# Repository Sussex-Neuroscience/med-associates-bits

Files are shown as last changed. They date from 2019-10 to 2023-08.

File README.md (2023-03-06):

# Med Associates open source add ons and bits

 Med Associates sells a number of tools for behavioural systems. This commercial system is a complete solution for behavioural experiments, and can be used to run multiple behavioural boxes in parallel. It is unfortunately rather expensive and closed source, so users are almost always dependent on MedAssociates for upgrades and customization (and whenever something breaks). Another downside is that an unusual 28V system is employed, so adding/customizing things has an extra layer of complexity.

 This repository is a collection of bits, add-ons and some knowledge on the system we have gathered over the years.
 
### [License](./LICENSE)

### [Code of Conduct](./code_of_conduct.md)

### [Contributing](./contributing.md)

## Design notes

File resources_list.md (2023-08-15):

# A list with links and descriptions of useful resources.

|item|link|obs|
|--|--|--|
|clickers|https://uk.rs-online.com/web/p/power-relays/6133617|any relay capable of handling 24V as the trigger for the coil should be able to do the trick, make sure to attach a diode, like one from ln400X family|
|cable connector housing male|||
|cable connector|https://uk.rs-online.com/web/p/crimp-contacts/2363044/||
||||
||||
||||

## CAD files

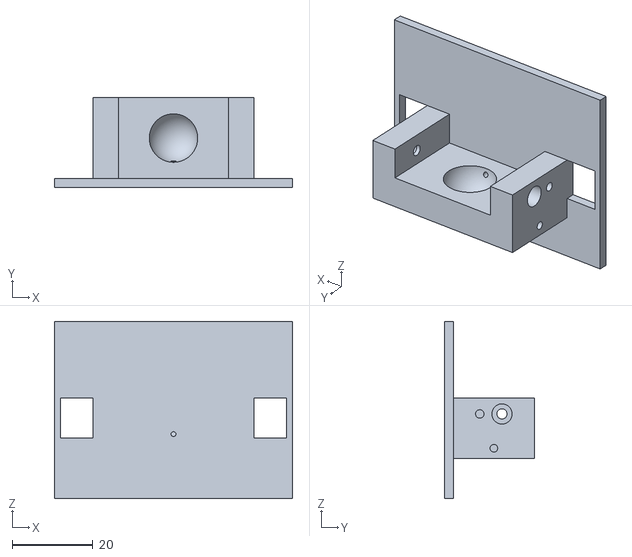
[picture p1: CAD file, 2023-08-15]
hardware/Head entry draft 2.stl
59.0 x 22.2 x 44.0

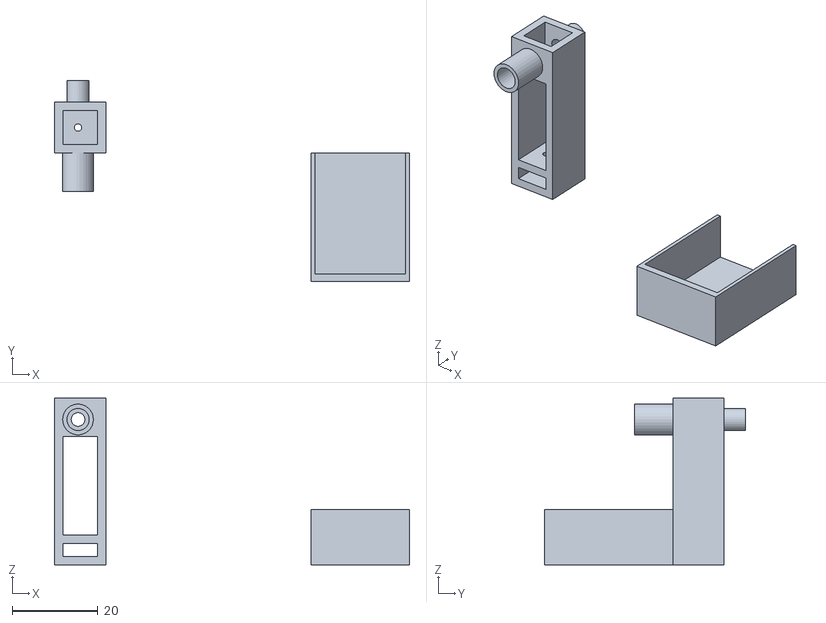
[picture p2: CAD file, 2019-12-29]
hardware/liking_spout/supports.stl
83.0 x 47.0 x 39.0

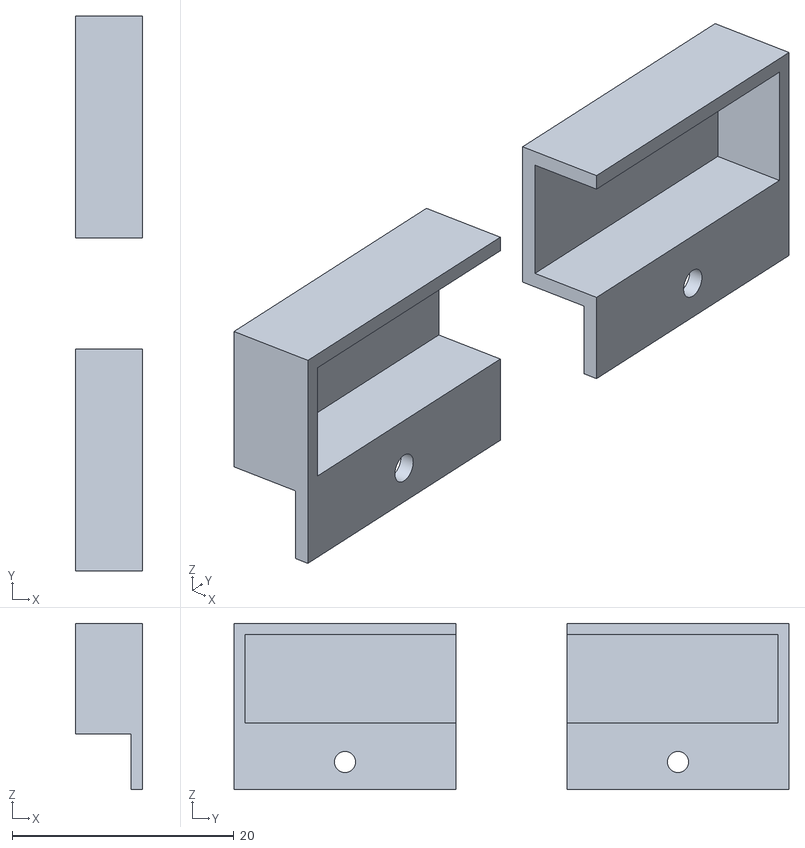
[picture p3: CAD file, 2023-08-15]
hardware/head entry photocell protectors.stl
6.00 x 50.0 x 15.0

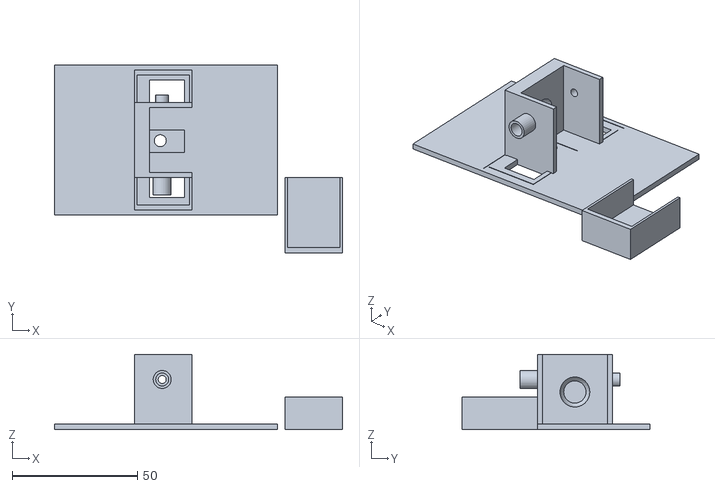
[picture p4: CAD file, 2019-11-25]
hardware/liking_spout/licking_spout_photometry.stl
115.0 x 74.9 x 30.0

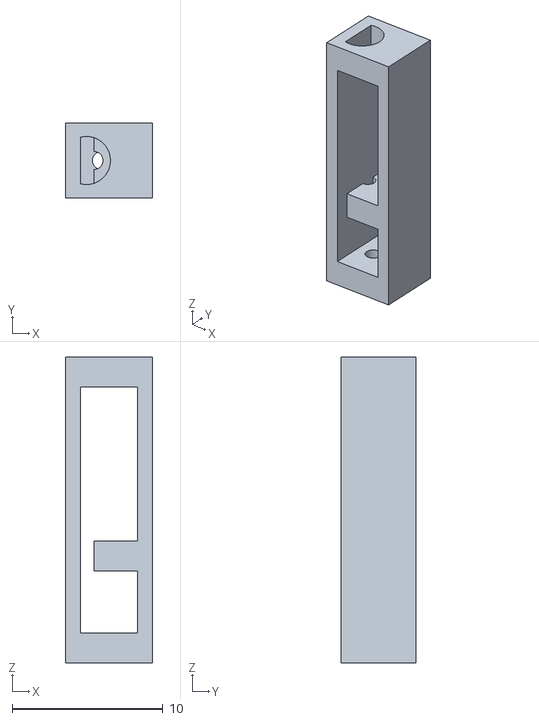
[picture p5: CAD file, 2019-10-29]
hardware/liking_spout/test1.stl
5.80 x 5.00 x 20.3

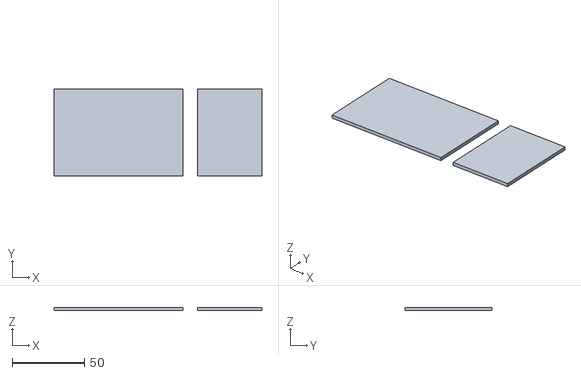
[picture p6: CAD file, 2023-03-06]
hardware/plates.stl
143.5 x 60.0 x 2.30

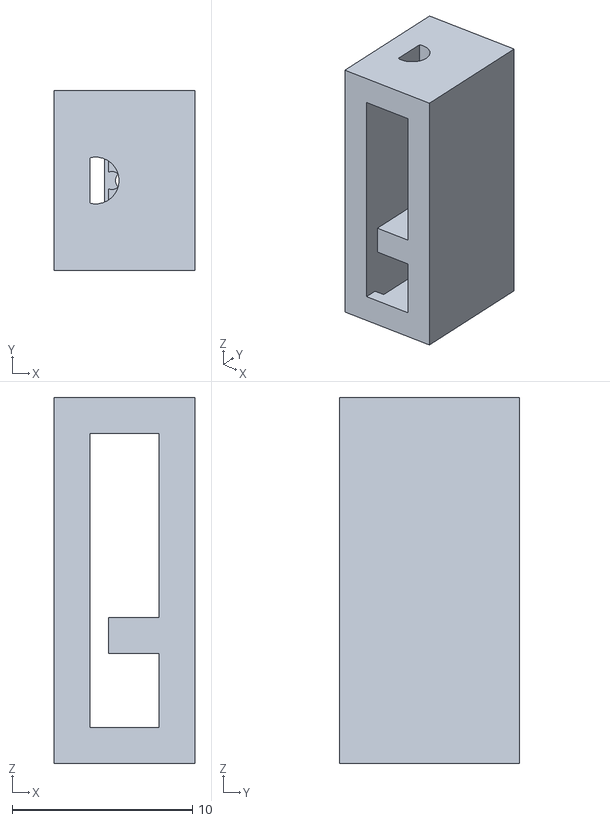
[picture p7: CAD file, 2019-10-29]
hardware/liking_spout/test.stl
7.80 x 10.0 x 20.3

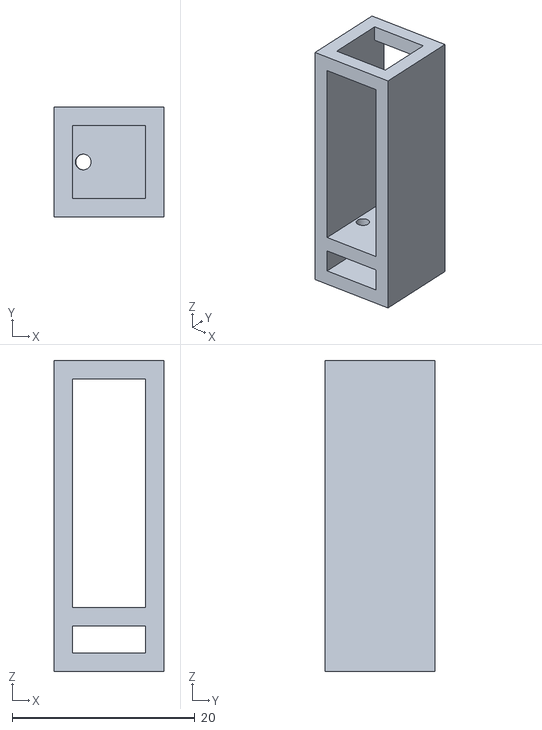
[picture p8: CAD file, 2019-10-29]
hardware/liking_spout/licking_spout_tilted.stl
12.0 x 12.0 x 34.0

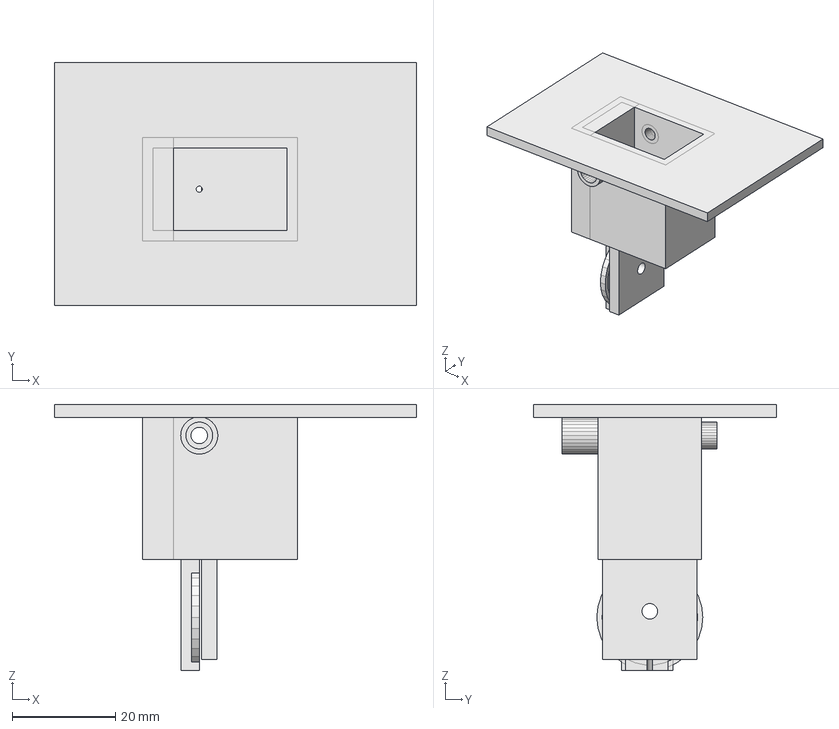
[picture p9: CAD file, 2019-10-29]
hardware/liking_spout/licking_spout.FCStd
70.0 x 47.0 x 51.5 mm

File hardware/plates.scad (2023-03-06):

tol = 0.1;
lPlateL = 89;
sPlateL = 44.5;
plateW = 60;


plateT = 2.3;

cube([lPlateL,plateW,plateT]);

translate([lPlateL+10,0,0])
cube([sPlateL,plateW,plateT]);

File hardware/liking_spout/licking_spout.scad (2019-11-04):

///////////////////////////////////////////
// Design for a liking spout to be used  //
// in the behaviour box                  //
//  CC-BY-SA 4.0 20191008                //
//  Andre Maia Chagas                    //
///////////////////////////////////////////

// all dimensions in mm.

//needs the ring.scad file (saved on the same folder)
use <ring.scad>

//// variables /////////////

//needle used as licking spout
needlediameter = 1.53;

//back plate dimensions 
//(the plate that slides on the metal railings)
backpanelx = 44.5*2;
backpanely = 59.80;
backpanelz = 2.15;

supportw=5;

//dimensions for the headport 
//(a "negative" space where the licking spout will be placed)
headportx = 30;
headporty = 20;
headportz = 30;
lickspoutoffset = 5;
//wall thickness
headportwall = 2;


//force sensor dimensions
forcesensord = 18.3;
forcesensorh = 0.8;
forcesensorl = 33; //how long the long part of the sensor
forcesensorw = 8; // wiidth of the long part of the sensor

//infrared led dimensions
irrecd = 3;
irrech = 5;
irledd = 5;
irledh = 9;

//nut & screw infor
screwd = 3.2;
nutd = 5;

/* change this depending on the printer and printer settings
   it is a "tolerance" variable, so holes and fittings can be 
   adjusted.
*/
tol = 0.1;

$fn=30;
//%cube([backpanelx,backpanely,backpanelz]);


//supporting modules
module irholes(){
    rotate([90,0,0]){
        translate([0,0,0]){
            cylinder(d=irledd+2*tol,h=irledh);
        }//end translate
        translate([0,0,-headporty]){    
            cylinder(d=irrecd+2*tol,h=irledh);
        }//end translate
     }//end rotate
}//end module ir holes

module irsupports(){
rotate([90,0,0]){
    translate([0,0,headportwall]){
ring(irledd+2*tol,2,irledh);
    }//end translate
translate([0,0,-headporty+headportwall/2]){    
    ring(irrecd+2*tol,2,irrech);
    }//end translate
}//end rotate
}//end module ir holes



module fsensorholder(){
difference(){
union(){
    cylinder(d=forcesensord+2*tol+headportwall,h=forcesensorh+headportwall/2);
    translate([-4.5,-13,-2]){
        cube([forcesensorw+headportwall,forcesensord+5,forcesensorh+headportwall/2+2]);
    }//end translate
}//end union

union(){
    translate([0,0,forcesensorh/2+headportwall/2]){
        cylinder(d=forcesensord+2*tol,h=forcesensorh);
    }//end translate
    translate([(-forcesensorw+headportwall/2)/2,0,(forcesensorh+headportwall)/2]){
        cube([forcesensorw+2*tol,forcesensorl+headportwall,5]);
    }//end translate
    translate([needlediameter/2,headporty/2+2,needlediameter/4+headportwall/2]){
        rotate([90,0,0]){
            cylinder(d=needlediameter+2*tol,h=55);
        }//end rotate
    }//end translate
}//end union

}//end difference

}//end module



/////////////////////////////
module needlesupport(){
    module mainframe(){
difference(){
cube([8+2*headportwall,forcesensorw+2*headportwall,35+2*headportwall]);
translate([headportwall,-headportwall,headportwall]){
cube([8,forcesensorw+4*headportwall,28]);
}//end translate
}//end difference
translate([headportwall,0,5]){
cube([8,forcesensorw+2*headportwall,headportwall]);
}//end translate
}//end submodule

difference(){
mainframe();
//translate([13.5,(forcesensorw+2*headportwall)/2,12]){
//rotate([0,90,0]){    
//%cylinder(d=nutd+2*tol,h=4,$fn=6);
//    translate([0,0,-6]){
//cylinder(d=screwd,h=12);
//}//rotate
//}//translate
//cube([nutd,nutd+10,nutd+tol],center=true);
//}//translate
translate([irrecd/2+2*headportwall,(forcesensorw+2*headportwall)/2,-headportwall-1]){
    rotate([0,0,0]){
        cylinder(d=needlediameter+2*tol,h=20);
    }//end rotate
    translate([0,0,35+headportwall]){
    rotate([90,0,0]){
        
        cylinder(d=irledd+2*tol,h=20);
        
    }//end rotate
    rotate([-90,0,0]){
        
        cylinder(d=irrecd+2*tol,h=20);
        
    }//end rotate
    }//end translate
}//end translate



translate([headportwall,headportwall,10]){
        cube([8,forcesensorw,30]);
        
    }//end translate
    
}//end difference
translate([(8+headportwall)/2+0.5,0,35+headportwall-irledd/2-0.5]){
rotate([90,0,0]){
ring(irledd+2*tol,2,irledh);
}//end rotate
}//end translate
translate([(8+headportwall)/2+0.5,forcesensorw+2*headportwall,35+headportwall-irrecd]){
rotate([-90,0,0]){
ring(irrecd+2*tol,2,irrech);

}//end rotate
}//end translate
//}//end translate
}//end module




/////////////////////////////
module lickingport(){
//head port
difference(){
cube([headportx,headporty,headportz]);
    
    
union(){    
translate([headportwall,headportwall,headportwall]){
cube([headportx-headportwall*2,headporty-headportwall*2,headportz]);
}//end translate


//needle entry
translate([headportx/5+lickspoutoffset-needlediameter/2,(headporty-headportwall+needlediameter)/2,-35]){
    cylinder(d=3*needlediameter+2*tol,h=50);
    }//end translate
 
    //led side ports
    translate([headportx/5+5,headportwall+2,4*headportz/5]){
        irholes();
    }//end translate
}//end union
}//end difference
///////////////////////

////////////////////////////
    
///////////////////////////
//base plate with round liquid reservoir


difference(){ 
cube([headportx/5,headporty,headportz]);
translate([headportx/5,headporty/2,3*headportz/6]){
    sphere(d=12);
    }//end translate
}//end difference
    
////////////////////////////

translate([headportx/5+5,headportwall+2,4*headportz/5]){
irsupports();
}
}//end licking port


module backpanel(){
difference(){
translate([-(headportx+2*headportwall)/2,-backpanely/2+headporty/2,headportz-headportwall-0.15]){

cube([backpanelx,backpanely,backpanelz]);
    

}
translate([0,0,5]){
cube([headportx,headporty,headportz]);
}//end transalte
}//end difference
}//end module


///////////////////////////
lickingport();
backpanel();
///////////////////////////

translate([5,headporty/2-(forcesensorw+2*headportwall)/2,-(35+2*headportwall)]){
//rotate([0,0,180]){
//fsensorholder();
needlesupport();
//}//end rotate
}//end translate


//
//needlesupport();

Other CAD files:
hardware/liking_spout/licking_spout_photometry.scad
hardware/liking_spout/ring.scad
hardware/liking_spout/licking_spout.stl

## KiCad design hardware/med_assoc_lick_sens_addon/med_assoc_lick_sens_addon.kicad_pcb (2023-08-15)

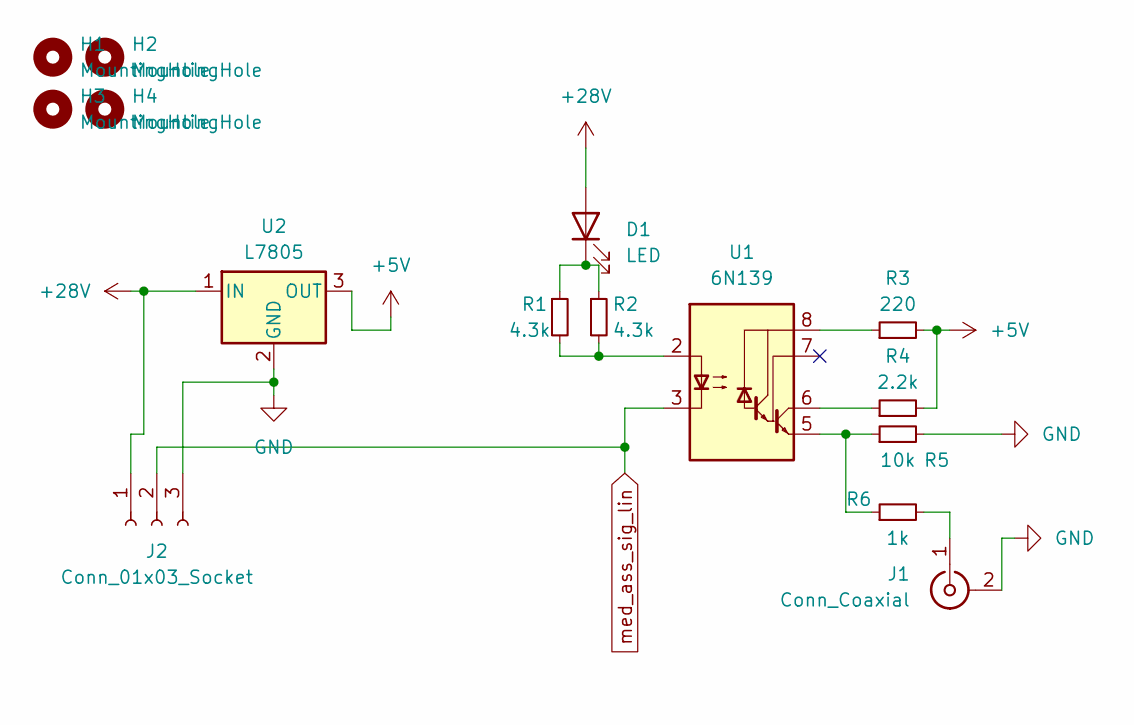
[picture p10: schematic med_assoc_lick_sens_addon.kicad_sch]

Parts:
D1: LED; LED_D5.0mm
H1, H2, H3, H4: MountingHole; MountingHole_3.2mm_M3
J1: Conn_Coaxial; TerminalBlock_Altech_AK300-2_P5.00mm
J2: Conn_01x03_Socket; TerminalBlock_Altech_AK300-3_P5.00mm
R1, R2: 4.3k; R_Axial_DIN0309_L9.0mm_D3.2mm_P12.70mm_Horizontal
R3: 220; R_Axial_DIN0309_L9.0mm_D3.2mm_P12.70mm_Horizontal
R4: 2.2k; R_Axial_DIN0309_L9.0mm_D3.2mm_P12.70mm_Horizontal
R5: 10k; R_Axial_DIN0309_L9.0mm_D3.2mm_P12.70mm_Horizontal
R6: 1k; R_Axial_DIN0309_L9.0mm_D3.2mm_P12.70mm_Horizontal
U1: 6N139; DIP-8_W7.62mm_LongPads
U2: L7805; TO-220-3_Vertical

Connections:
+5V: R3.2, R4.2, U2.3 (OUT)
+28V: D1.2 (A), J2.1, U2.1 (IN)
GND: J1.2 (Ext), J2.3, R5.2, U2.2 (GND)
unnamed: D1.1 (K), R1.1, R2.1
unnamed: J1.1 (In), R6.2
unnamed: R1.2, R2.2, U1.2 (C1)
unnamed: R5.1, R6.1, U1.5 (GND)
unnamed: R3.1, U1.8 (VCC)
unnamed: R4.1, U1.6 (VO2)
med_ass_sig_lin: J2.2, U1.3 (C2)

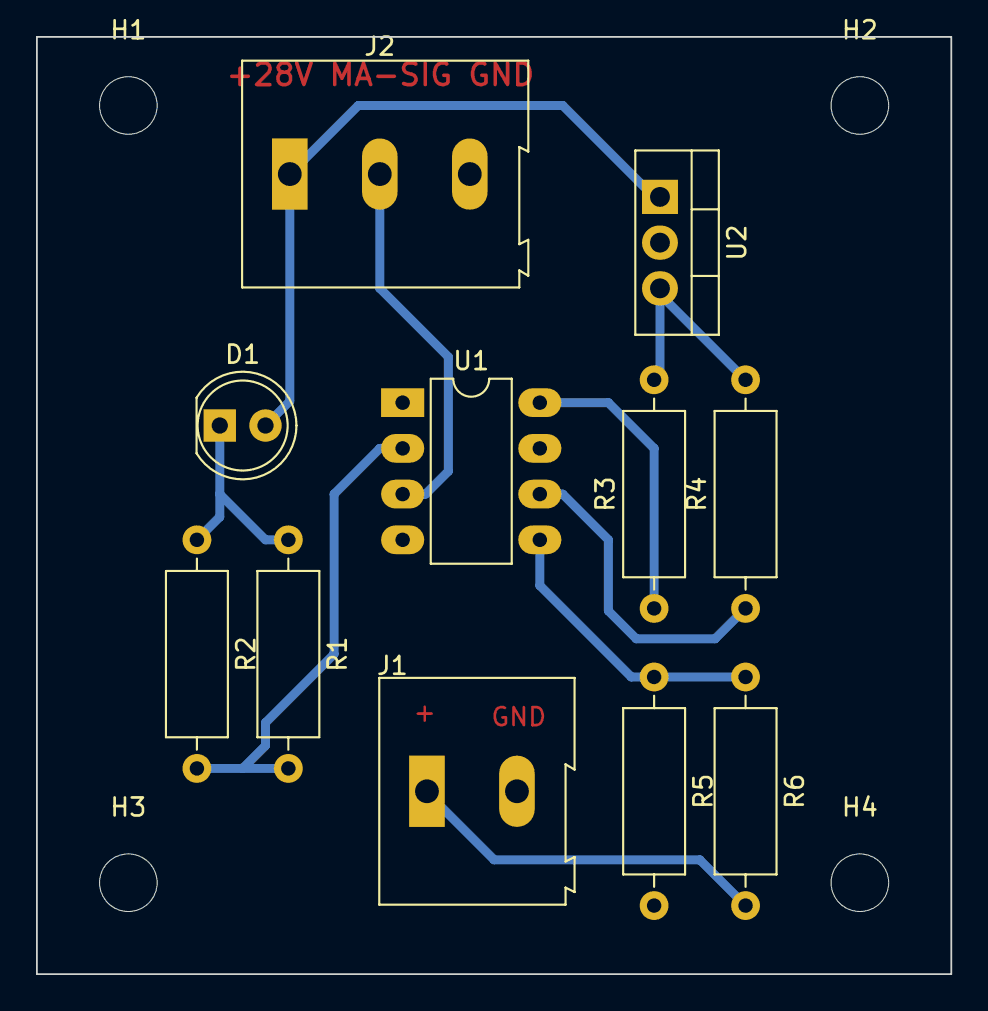
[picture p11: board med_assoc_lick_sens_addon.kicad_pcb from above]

Board: 2 copper layers, 50.8 x 52.1 mm, 15 parts (0 on the bottom side), 10 nets.

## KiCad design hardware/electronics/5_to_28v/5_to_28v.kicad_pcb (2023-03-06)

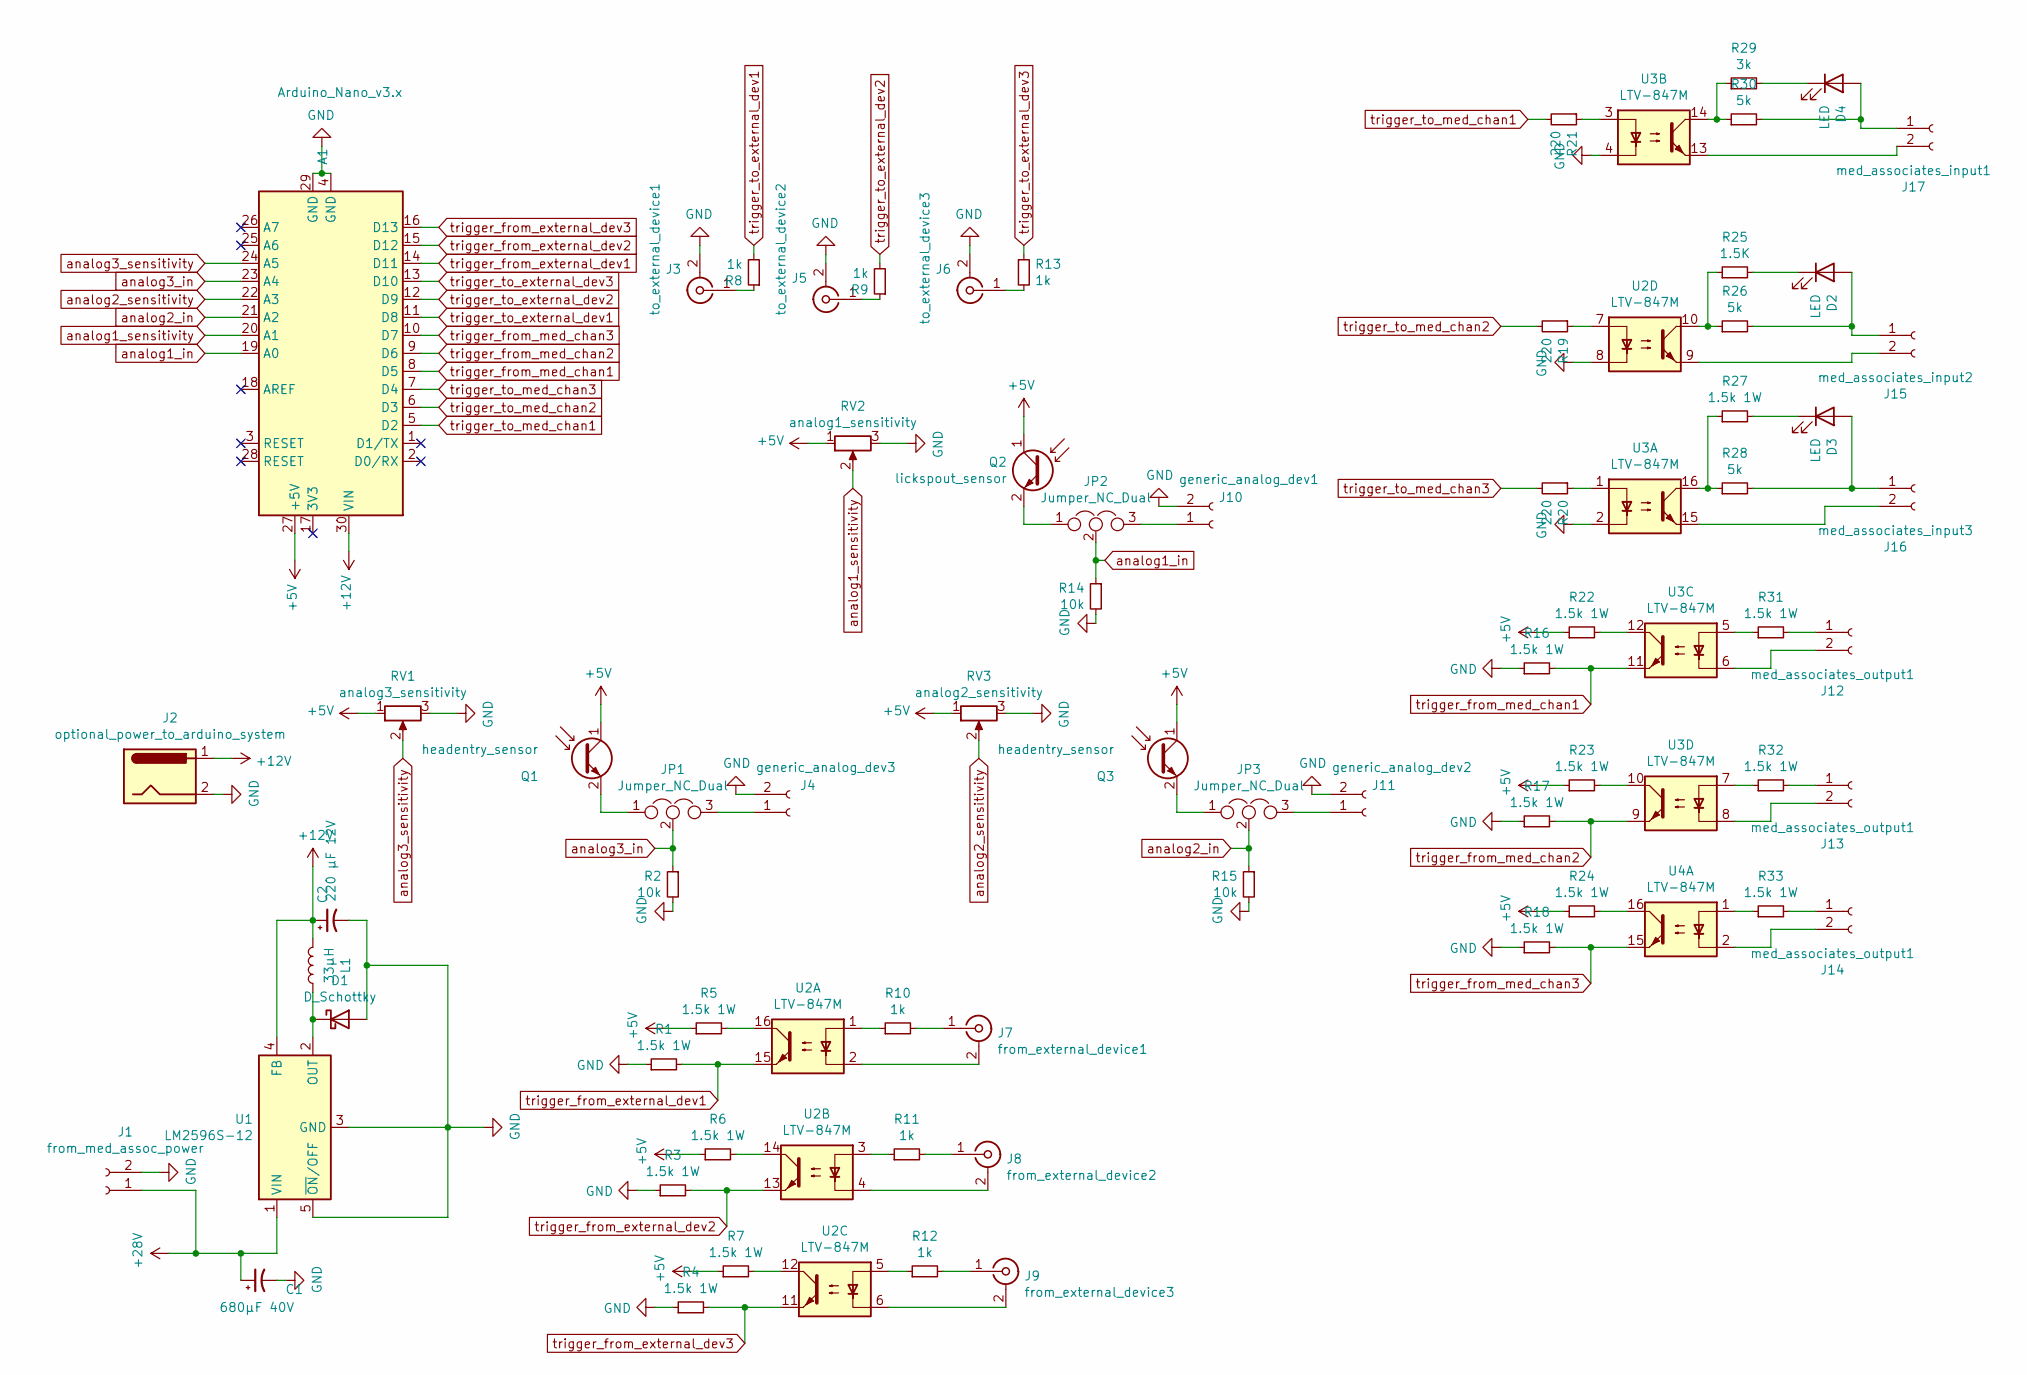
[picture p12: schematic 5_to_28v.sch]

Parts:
A1: Arduino_Nano_v3.x; Arduino_Nano
C1: 680µF 40V; CP_Radial_D10.0mm_P5.00mm_P7.50mm
C2: 220 µF 12V; CP_Radial_D10.0mm_P5.00mm_P7.50mm
D1: D_Schottky; D_DO-27_P15.24mm_Horizontal
D2, D3, D4: LED; LED_D5.0mm
J1: from_med_assoc_power; JST_XH_B2B-XH-A_1x02_P2.50mm_Vertical
J2: optional_power_to_arduino_system; BarrelJack_Horizontal
J3: to_external_device1; JST_XH_B2B-XH-A_1x02_P2.50mm_Vertical
J4: generic_analog_dev3; JST_XH_B2B-XH-A_1x02_P2.50mm_Vertical
J5: to_external_device2; JST_XH_B2B-XH-A_1x02_P2.50mm_Vertical
J6: to_external_device3; JST_XH_B2B-XH-A_1x02_P2.50mm_Vertical
J7: from_external_device1; JST_XH_B2B-XH-A_1x02_P2.50mm_Vertical
J8: from_external_device2; JST_XH_B2B-XH-A_1x02_P2.50mm_Vertical
J9: from_external_device3; JST_XH_B2B-XH-A_1x02_P2.50mm_Vertical
J10: generic_analog_dev1; JST_XH_B2B-XH-A_1x02_P2.50mm_Vertical
J11: generic_analog_dev2; JST_XH_B2B-XH-A_1x02_P2.50mm_Vertical
J12, J13, J14: med_associates_output1; JST_XH_B2B-XH-A_1x02_P2.50mm_Vertical
J15: med_associates_input2; JST_XH_B2B-XH-A_1x02_P2.50mm_Vertical
J16: med_associates_input3; JST_XH_B2B-XH-A_1x02_P2.50mm_Vertical
J17: med_associates_input1; JST_XH_B2B-XH-A_1x02_P2.50mm_Vertical
JP1, JP2, JP3: Jumper_NC_Dual; PinHeader_1x03_P2.54mm_Vertical
L1: 33µH; L_Radial_D7.5mm_P3.50mm_Fastron_07P
Q1, Q3: headentry_sensor; LED_D5.0mm
Q2: lickspout_sensor; LED_D5.0mm
R1, R3, R4, R5, R6, R7, R16, R17, R18, R22, R23, R24, R27, R31, R32, R33: 1.5k 1W; R_Axial_DIN0516_L15.5mm_D5.0mm_P25.40mm_Horizontal
R2, R14, R15: 10k; R_Axial_DIN0516_L15.5mm_D5.0mm_P25.40mm_Horizontal
R8, R9, R10, R11, R12, R13: 1k; R_Axial_DIN0411_L9.9mm_D3.6mm_P15.24mm_Horizontal
R19, R20, R21: 220; R_Axial_DIN0411_L9.9mm_D3.6mm_P15.24mm_Horizontal
R25: 1.5K; R_Axial_DIN0516_L15.5mm_D5.0mm_P25.40mm_Horizontal
R26, R28, R30: 5k; R_Axial_DIN0516_L15.5mm_D5.0mm_P25.40mm_Horizontal
R29: 3k; R_Axial_DIN0516_L15.5mm_D5.0mm_P25.40mm_Horizontal
RV1: analog3_sensitivity; JST_XH_B3B-XH-A_1x03_P2.50mm_Vertical
RV2: analog1_sensitivity; JST_XH_B3B-XH-A_1x03_P2.50mm_Vertical
RV3: analog2_sensitivity; JST_XH_B3B-XH-A_1x03_P2.50mm_Vertical
U1: LM2596S-12; TO-220-5_P3.4x3.7mm_StaggerOdd_Lead3.8mm_Vertical
U2, U3, U4: LTV-847M; DIP-16_W10.16mm

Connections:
+5V: A1.27 (+5V), Q1.1 (C), Q2.1 (C), Q3.1 (C), R5.1, R6.1, R7.1, R22.1, R23.1, R24.1, RV1.1, RV2.1, RV3.1
+12V: A1.30 (VIN), C2.1, J2.1, L1.2, U1.4 (FB)
+28V: C1.1, J1.1, U1.1 (VIN)
GND: A1.4 (GND), A1.29 (GND), C1.2, C2.2, D1.2 (A), J1.2, J2.2, J3.2 (Ext), J4.2, J5.2 (Ext), J6.2 (Ext), J10.2, J11.2, R1.1, R2.2, R3.1, R4.1, R14.2, R15.2, R16.1, R17.1, R18.1, RV1.3, RV2.3, RV3.3, U1.3 (GND), U1.5 (~ON~/OFF), U2.8, U3.2, U3.4
unnamed: D1.1 (K), L1.1, U1.2 (OUT)
unnamed: D2.1 (K), R25.2
unnamed: D2.2 (A), J15.1, R26.2
unnamed: D3.1 (K), R27.2
unnamed: D3.2 (A), J16.1, R28.2
unnamed: D4.1 (K), R29.2
unnamed: D4.2 (A), J17.1, R30.2
unnamed: J3.1 (In), R8.1
unnamed: J4.1, JP1.3
unnamed: J5.1 (In), R9.1
unnamed: J6.1 (In), R13.2
unnamed: J7.1 (In), R10.2
unnamed: J7.2 (Ext), U2.2
unnamed: J8.1 (In), R11.2
unnamed: J8.2 (Ext), U2.4
unnamed: J9.1 (In), R12.2
unnamed: J9.2 (Ext), U2.6
unnamed: J10.1, JP2.3
unnamed: J11.1, JP3.3
unnamed: J12.1, R31.2
unnamed: J12.2, U3.6
unnamed: J13.1, R32.2
unnamed: J13.2, U3.8
unnamed: J14.1, R33.2
unnamed: J14.2, U4.2
unnamed: J15.2, U2.9
unnamed: J16.2, U3.15
unnamed: J17.2, U3.13
unnamed: JP1.1, Q1.2 (E)
unnamed: JP2.1, Q2.2 (E)
unnamed: JP3.1, Q3.2 (E)
unnamed: R5.2, U2.16
unnamed: R6.2, U2.14
unnamed: R7.2, U2.12
unnamed: R10.1, U2.1
unnamed: R11.1, U2.3
unnamed: R12.1, U2.5
unnamed: R19.1, U2.7
unnamed: R20.1, U3.1
unnamed: R21.1, U3.3
unnamed: R22.2, U3.12
unnamed: R23.2, U3.10
unnamed: R24.2, U4.16
unnamed: R25.1, R26.1, U2.10
unnamed: R27.1, R28.1, U3.16
unnamed: R29.1, R30.1, U3.14
unnamed: R31.1, U3.5
unnamed: R32.1, U3.7
unnamed: R33.1, U4.1
analog1_in: A1.19 (A0), JP2.2, R14.1
analog1_sensitivity: A1.20 (A1), RV2.2
analog2_in: A1.21 (A2), JP3.2, R15.1
analog2_sensitivity: A1.22 (A3), RV3.2
analog3_in: A1.23 (A4), JP1.2, R2.1
analog3_sensitivity: A1.24 (A5), RV1.2
trigger_from_external_dev1: A1.14 (D11), R1.2, U2.15
trigger_from_external_dev2: A1.15 (D12), R3.2, U2.13
trigger_from_external_dev3: A1.16 (D13), R4.2, U2.11
trigger_from_med_chan1: A1.8 (D5), R16.2, U3.11
trigger_from_med_chan2: A1.9 (D6), R17.2, U3.9
trigger_from_med_chan3: A1.10 (D7), R18.2, U4.15
trigger_to_external_dev1: A1.11 (D8), R8.2
trigger_to_external_dev2: A1.12 (D9), R9.2
trigger_to_external_dev3: A1.13 (D10), R13.1
trigger_to_med_chan1: A1.5 (D2), R21.2
trigger_to_med_chan2: A1.6 (D3), R19.2
trigger_to_med_chan3: A1.7 (D4), R20.2

Board: 2 copper layers, 71 parts (0 on the bottom side), 71 nets, no tracks yet.

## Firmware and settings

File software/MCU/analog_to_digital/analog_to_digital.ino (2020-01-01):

////////////////////////////////////////////////////////
// Adaptor system for Med Associates behavioural box  //
// This code is to be used to convert  analog signals //
// to digital.                                        //
// it takes analog inputs, and compares them to user  //
// defined thresholds (set via potentiometers or      //
// software), and outputs digital signals             //
// there are also indicator digital signals that are  //
// turned on together with the output signals         //
//                                                    //
// Created by AM Chagas 20191210 CC BY SA             //
////////////////////////////////////////////////////////


//define pins///////////////////////////////

//analog input ports//////
// infrared detectors
int IRrecPin = A0;
int IRrecPin1 = A2;
//potentiomenter pin
int comparatorPin = A1;
//digital output 0
int digOutPin = 13;
// digital output 1
int digOutPin1 = 12;
// led indicator 0
int ledInd = 2;
// led indicator 1
int ledInd1= 3;
// variable to store infrared detector0 readout
int IRread = 0;
// variable to store comparator number
int compRead = 0;
// variable to store infrared detector1 readout
int IRread1 = 0;
//variable to store comparator number
int compRead1 = 0;


//things that are going to run on the very beginning
void setup() {
  //start serial port at 9600 baud rate
  Serial.begin(9600);
  //set digital port to output
  pinMode(digOutPin, OUTPUT);
  //set digital port to output
  pinMode(digOutPin1, OUTPUT);
  //set digital port to output
  pinMode(ledInd, OUTPUT);
  //set digital port to output
  pinMode(ledInd1, OUTPUT);



}

//here the code that is going to run forever
void loop() {
  //red the infrared detector port
  IRread = analogRead(0);
  //read the value on the potentiometer
  compRead = analogRead(1);
  //read the value on infrared detector 1 port
  IRread1 = analogRead(2);
  //use the serial port to send data to the computer
  //Serial.print("IR sensor: ");
  //Serial.println(IRread1);

  //Serial.print("IR sensor: ");
  //Serial.println(IRread);
  //Serial.print("pote: ");
  //Serial.println(compRead);

  //compare values of infrared detector 0 and potentiomenter.
  // if the treshold is crossed, send a digital signal out, and
  // turn on the indicator led
  if (IRread>=compRead){
    digitalWrite(digOutPin, HIGH);
    digitalWrite(ledInd, HIGH);
    }
  //if the the threshold is not crossed, turn the digital signal off
  // as well as the indicator led
  else{
    digitalWrite(digOutPin, LOW);
    digitalWrite(ledInd, LOW);
  }
  // the infrared detector 1 uses a fixed, software defined threshold
  //below is the same comparison code as above
  if (IRread1>=512){
    digitalWrite(digOutPin1, LOW);
    digitalWrite(ledInd1, LOW);
    }
  else{
    digitalWrite(digOutPin1, HIGH);
    digitalWrite(ledInd1, HIGH);
  }

}

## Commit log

2019-10-29 developing a licking spout port. mechanics
    [licking_spout.FCStd, licking_spout.scad, licking_spout.stl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]
2019-10-29 more testing with licking spout
    [licking_spout.scad, licking_spout.stl]
2019-11-04 add bits and bops that will help the behavioural box
    [grid_support.scad, grid_support.stl, licking_spout.scad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]
2019-11-25 changed the electronics schematics for the 5to28V converter, created the licking spout for animals implanted with photometry fibers and made a printed part to subsitute a plexiglass grid holder that 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
    [5_to_28v.kicad_pcb, 5_to_28v.sch, grid_support1.stl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]
2019-11-29 Update analog_to_digital.ino
    so that two led indicators are reporting the animal's interaction with the device.
2019-12-29 add changesto arduino and hardware
    [5_to_28v.sch, licking_spout_photometry.scad, supports.stl]
2020-01-01 updated comments on arduino code
2020-01-13 clean up repository
    [grid_support.scad, grid_support.stl, grid_support1.stl]
2020-08-03 add baords and updates to code
    [5_to_28v.sch]
2020-08-11 first implementation of a generic solution
    [5_to_28v.kicad_pcb, 5_to_28v.sch]
2023-03-06 add plates design
    [plates.scad, plates.stl]
2023-03-06 rename and update repo to be more of a general system to deposit med-ass info
    [licking_spout.FCStd, licking_spout.scad, licking_spout.stl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]
2023-07-12 create schematics and pcb for lick sensor addon
    [med_assoc_lick_sens_addon-B_Cu.gbr, med_assoc_lick_sens_addon-B_Mask.gbr, med_assoc_lick_sens_addon-B_Paste.gbr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]
2023-07-13 move traces to bottom side of board
    [med_assoc_lick_sens_addon-B_Cu.gbr, med_assoc_lick_sens_addon-B_Mask.gbr, med_assoc_lick_sens_addon-B_Paste.gbr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]
2023-07-17 update traces and other bits
    [Head entry draft 2.stl, head entry photocell protectors.stl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]
